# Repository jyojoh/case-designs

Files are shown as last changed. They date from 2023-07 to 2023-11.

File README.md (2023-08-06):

# case-designs
Repository containing STL/STEP files and documentation for my keyboard case designs.  

<p align="center">
<a href="https://discord.gg/P8n4zPxJH5">
  
</a>
</p>

> [!WARNING]
> Please read all enclosed information within the README files in each subfolder for the case that you want to use! There is vital information about battery compatibility, fasteners, and assembly instructions written for each case design!

## Currently Maintained Designs
1. [Choc 5-column Corne](/corne/5-column%20Choc)
2. [Choc 6-column Corne](/corne/6-column%20Choc)
3. MX 6-column Corne (Planned)
   
## Completed/Retired Projects

## Manufacturing Notes
> [!NOTE] 
>All images of cases displayed in this repository are of prototypes manufactured through the CNC-machining services provided by [PCBWay](https://pcbway.com). They are my preferred way for quickly getting prototypes. A lower-cost (and lower quality) alternative would be [JLCPCB](https://jlcpcb.com). Their manufacturing capabilities are more limited, cases received from them have had noticeable machining marks even after bead-blasting. Conversely, the resin 3D-printing services from [JLCPCB](https://jlcpcb.com) are excellent and provided at very reasonable cost. Would highly recommend ordering resin prints to check dimensional correctness, and then proceeding with CNC-machining after verifying. Resin printing is also well-suited for buttons and power switch sliders pieces.

## License
Individuals are free to use the files in this repository for the manufacturing of their own cases. For commercial use, all that is required is providing attribution to  the original designer and linking to this repository in materials distributed for the sales of cases manufactured from the design files here and any derivatives. Attribution materials include the notice in the root directory of this repository.

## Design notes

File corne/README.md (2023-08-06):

# Typeractive Corne
5-col preview
The subfolders here contain production files (.STEP, .STL) for the Corne PCBs found at [Typeractive](https://typeractive.xyz). Please read the following materials closely to ensure proper preparation of parts and subsequent assembly. 

## Introduction
### Required Components (Bare minimum useable keyboard)
1. Case (Left and Right Halves)
1. 2 x [Typeractive Corne PCB](https://typeractive.xyz/products/corne-partially-assembled-pcb)
1. 2 x [nice!nano v2](https://typeractive.xyz/products/nice-nano)
1. 2 x LiPo Batteries:
    - Standard Cases: 803450 1600mAh LiPo Battery 
    - Inset Cases: 503450 1000 mAh LiPo Battery
    - Flat/Legged Cases: 303450 600 mAh LiPo Battery
1. 36/42 x Kailh Choc v1 Switches (Quantities for 5-column/6-column)
1. 36/42 x Keycaps (Pictured are MCC POM)
1. 10 x Brass Standoffs:
    - Tented Cases: 4mm Female to 3mm Male M2 Standoffs
    - Inset Cases: 3mm Female to 3mm Male M2 Standoffs
1. 10 x M2x3mm Bolts
1. 10 x [M2x3mm Heatset Inserts](https://a.co/d/eyAmOag) **(Only if 3D-printing the Heatset Variants)**

### Optional Components **(Highly Recommended!)**
1. 2 x [nice!view Displays](https://typeractive.xyz/products/nice-view)
1. 2 x [Display Covers](displayCover.dxf)
1. 4 x M2x10mm Standoffs
1. 4 x Additional M2x3mm Bolts
1. 1+ x [buttonSlider.stl](buttonSlider.stl) or [buttonSliderSlim.stl](buttonSliderSlim.stl) (for slim cases) which includes already print-plated:
    - 2 x Power Switch Slider (3D-resin printed)
    - 2 x Reset Button Bumper (3D-resin printed)
1. 4 x SKUF Silicone Rubber Feet

All of the listed parts can be bought through Typeractive, except for the case components, fasteners, batteries, and SKUF feet. 

## Manufacturing Notes
1. You only need to print 1 x [buttonSlider.stl](buttonSlider.stl) or [buttonSliderSlim.stl](buttonSliderSlim.stl) depending on the case design, however it is recommended that you print at least one extra to accomodate any mistakes in the post-processing of the printed pieces. One print of the STL includes 2 x power sliders and 2 x reset bumpers to be cut/snapped apart.
2. Recommended manufacturer for the case is [PCBWay](https://pcbway.com), manufacturer for the printed button/slider is [JLCPCB](https://jlcpcb.com).
3. Material used for [buttonSlider.stl](buttonSlider.stl) and [buttonSliderSlim.stl](buttonSliderSlim.stl) is SLA "Black Resin", bead-blasted polycarbonate for the case in the included pictures.
1. **Machining the case designs using metal materials could result in connectivity issues, due to the signal wave-blocking properties of metal. Do so at your own risk!**

## Assembly
1. Assemble the keyboard sans-case as per the [documentation](https://docs.typeractive.xyz/build-guides/corne-wireless) on the Typeractive site.
2. Carefully screw female/male standoffs into each half of the case body. Be careful not to overtighten, and ensure it is perpendicular to the interior of the case!
3. Using flush cutters, separate the power slider and reset button extension from the 3D-printed part. 
4. Insert power slider and reset button extension into their respective slots in the case.
5. At an angle, slide the PCB/Plate assembly of the Corne into the case, ensuring the power switch and reset button on the PCB interface correctly with the slider/extension.
6. Bolt down PCB, apply switches and keycaps, flash as per the firmware [documentation](https://docs.typeractive.xyz/build-guides/corne-wireless)  on the Typeractive site.

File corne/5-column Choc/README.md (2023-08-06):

All case designs listed are derivatives of the "Standard" case. Unless otherwise noted, all case designs are tented by 5 degrees. 

5-col preview

## In this folder:

1. [Standard](/corne/5-column%20Choc/Standard): Tray Mount. 5mm thick walls, 1-piece design suitable for CNC or 3D-printing. 
1. [Standard-Flat](/corne/5-column%20Choc/Standard-Flat): Tray Mount. 5mm thick walls, non-tented. 1-piece design suitable for CNC or 3D-printing.
1. [Inset](/corne/5-column%20Choc/Inset): Tray Mount. In all aspects the same as the Standard case, except 1mm shorter in height. Requires 3mm standoffs instead of the usual 4mm. Suitable for CNC or 3D-printing.
1. [Flattest](/corne/5-column%20Choc/Inset-Flat): Tray Mount. In all aspects the same as the Standard case, just as flat and short as possible. Non-tented. Requires 3mm standoffs instead of the usual 4mm. Suitable for CNC or 3D-printing.
1. [Slim](/corne/5-column%20Choc/Slim): Tray Mount. 3mm thick walls, 1-piece design suitable for CNC or 3D-printing. 
1. [Slim-Flat](/corne/5-column%20Choc/Slim-Flat): Tray Mount. 3mm thick walls non-tented. 1-piece design suitable for CNC or 3D-printing. 
1. [Integrated](/corne/5-column%20Choc/Integrated): "Premium", designed with weight bottom in mind. Integrated Plate. 5mm thick walls, tented. 2-piece case design suitable for CNC machining.
1. [Legged](/corne/5-column%20Choc/Legged): Tray Mount. Includes protrusions that can optionally accept heat-set inserts for the installation of tenting legs. 5mm thick walls, 1-piece design suitable for CNC or 3D-printing. 

**Heatset variants of cases are included for FDM 3D-printing! The nominal hole size is 3.3mm, suitable for inserts with a 3.2mm OD.**
## CNC Data Preparation
When filling out the CNC manufacturing form through [PCBWay](https://pcbway.com), make sure to pay close attention to the following parameters:

1. Specify the desired surface finish. This will most likely be "bead-blasting". 
2. Specify that threaded holes are needed, and upload [threadDrawing.png](/corne/threadDrawing.png) to denote which holes need to be threaded for the M2 female/male standoffs.
3. If the surface finish of the part is of importance to you (it is for me), check the "Premium Finish" option. Note that this will result in a noticeable increase in price. 

## 3D-Printing Data Preparation
For a more budget-friendly version, you may choose to have the case along with the button and slider resin-printed instead through [JLCPCB](https://jlcpcb.com). Pay close attention to the follow parameters:

1. Specify the desired material. My choice for this would be SLA "Imagine Black".
2. You will notice that there is no "threading" option available on JLCPCB's 3D printing form. You will have to force-thread the standoffs yourself. This will almost certainly cause the holes to strip out first, an acceptable compromise as the friction should still hold the standoff firmly in place. 
3. Ensure that the sanding option is set to "Yes". This will greatly improve surface finish quality at little to no extra cost.

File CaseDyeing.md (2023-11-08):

# Dyeing Polycarbonate Cases

## Introduction
### Materials
1. Whichever polycarbonate case you want to dye
1. iDye Poly Dye Packet
1. Large pot (big enough to comfortably submerge your case entirely)
1. Suitable heat source, such as a stovetop
1. Thin Insulated wire
1. Mesh/Wire Basket to hold case, or large perforated ladle

When dyeing polycarbonate cases, there are 2 major factors that will dictate how quickly the color dye will penetrate the material: time, and temperature. The former is self-explanatory, the longer the item is submerged, the more the dye penetrates the material. For the latter, as temperature increases the dye will more easily penetrate the material. To illustrate, a case submerged in a near-boil solution of dye and water will be much darker than a case submerged in a lukewarm solution, when both are submerged for the same amount of time. 

### General Tips
1. Maintain constant agitation of the solution around the case in order to ensure an even coloring. 
1. Maintain constant temperature, or dye both pieces at once if working with multi-part case designs, to ensure even coloring. 
1. Ensure that the surrounding area is well-covered with waterproof materials, as any droplets of dye will quickly color surfaces that it comes into contact with, clothing included. 

> [!WARNING]  
> Always ensure that the solution remains below the boiling point! Boiling the solution will cause droplets of dye to fly out of the container and potentially permanently color the surrounding surfaces. 

> [!Important]
> Rinse the cases thoroughly after each application of dye. The cases will appear to be much darker in color upon first raising them out of the dye solution, however much of this color washes out. 

## Steps
1. Drop the iDye Poly dye pack into a volume of water that comfortably covers your polycarbonate case pieces when they are resting on the ladle at the bottom of the pot. 

> [!Note]
> If you desire a "solid", dark color, then you can opt to apply the dye strengthener pack as well. This will allow the dye to very quickly penetrate the material, resulting in a much darker color. 

2. Bring the solution to a simmer. Wait for all of the dye to completely dissolve into solution. 
1. Using the ladle or mesh basket, lower the pieces into the solution. Start a timer. 
1. Continuously agitate the solution around the case by:
    - Tying the thin wire around the USB port cutout, and jostling it continuously in the solution. Take care that the surface of the wire is insulated, as to prevent bare metal from scratching the case around the cutout. Additionally, ensure that the wire is thin enough to freely move in the port cutout, so as to not constantly be in contact with the interior faces, resulting in uneven dye coloring. 
    -  "Bouncing" the piece up and down by quickly lowering the ladle/basket, then catching the slower-falling case. Ensure that the surface of the ladle does not stay at the same point of contact with the case, as this may cause the ladle to become "imprinted" in the coloring of the case. 

> [!Important]
> Remember that polycarbonate is a relatively soft material when compared to the surfaces of any stainless steel utensils or the interior of the pot you are using! Take care in avoiding scrapes or harsh bumps when stirring and agitating the solution!

5. At regular intervals, such as every 3 minutes, take the case out and rinse thoroughly, revealing the true extent of the coloration. Scrubbing the case with your fingers is recommended. Stop and resume the timer every time this step is taken. Repeat until satisfied. 
1. If any additional parts need to be matched in color, repeat steps 3 to 5 until the piece matches in color to the first.

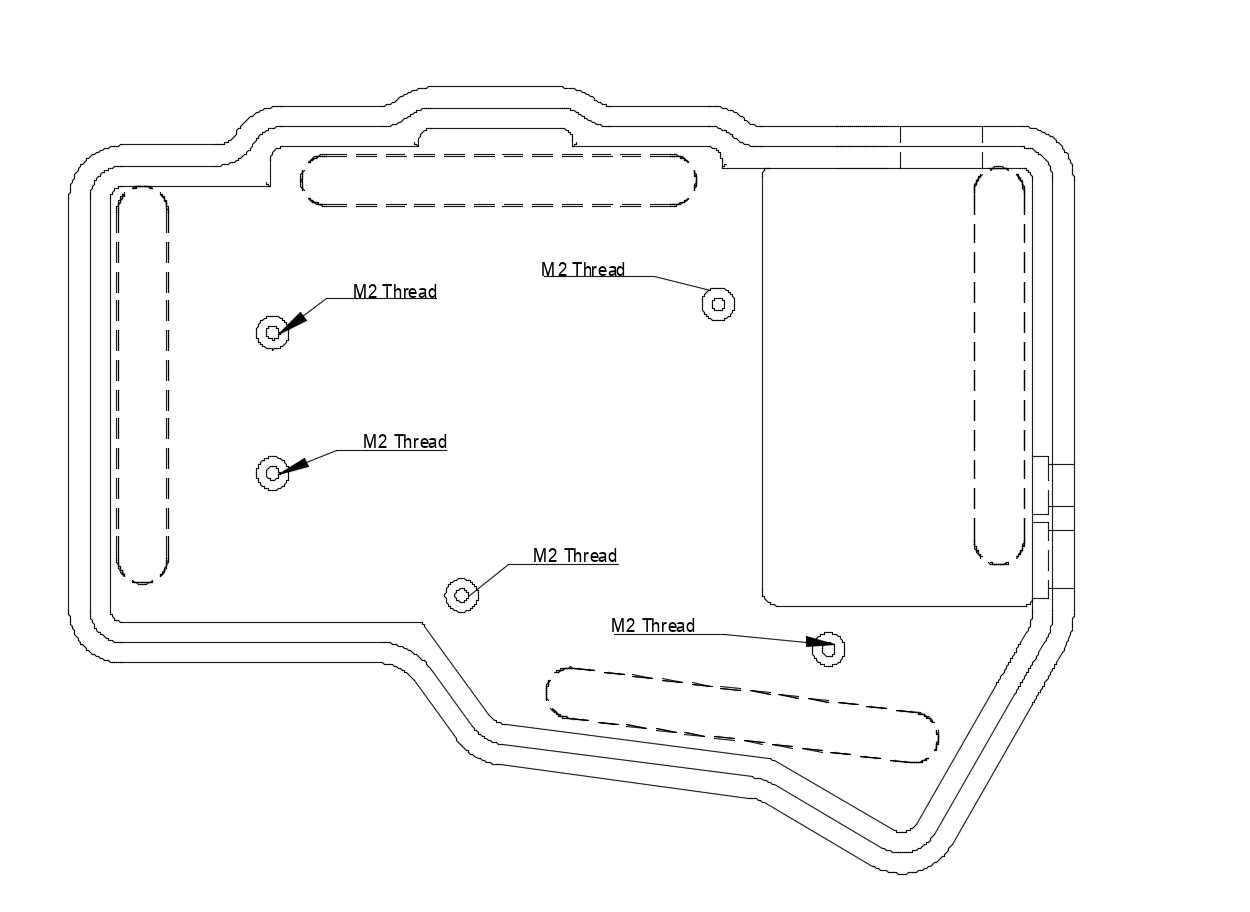
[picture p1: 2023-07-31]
corne/threadDrawing.png

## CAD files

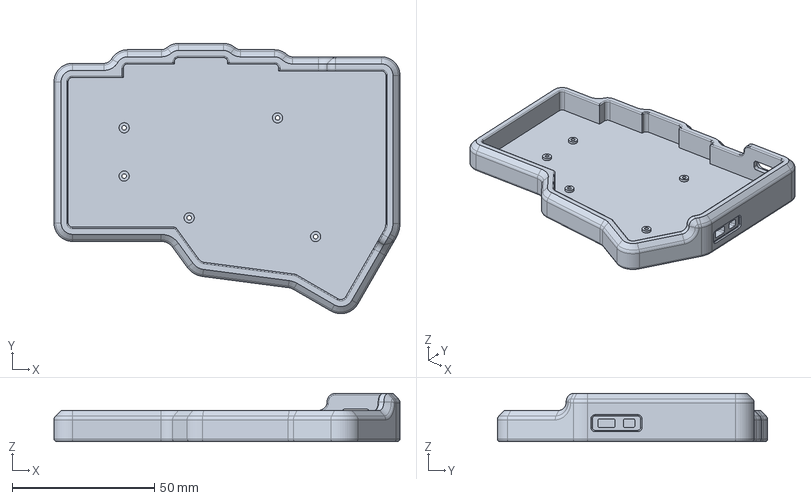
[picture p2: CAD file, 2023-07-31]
corne/5-column Choc/Flattest/leftFlattest.step
121.8 x 95.2 x 17.0 mm

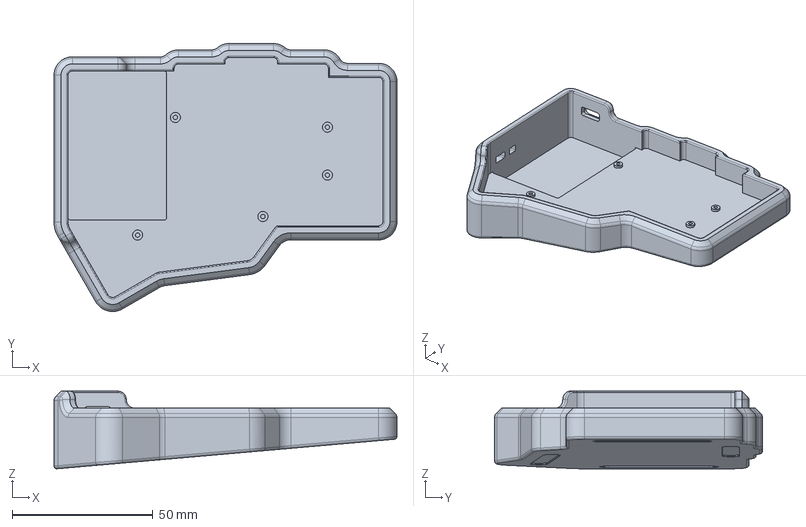
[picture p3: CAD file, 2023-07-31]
corne/5-column Choc/Inset/rightInset.step
121.8 x 95.2 x 27.6 mm

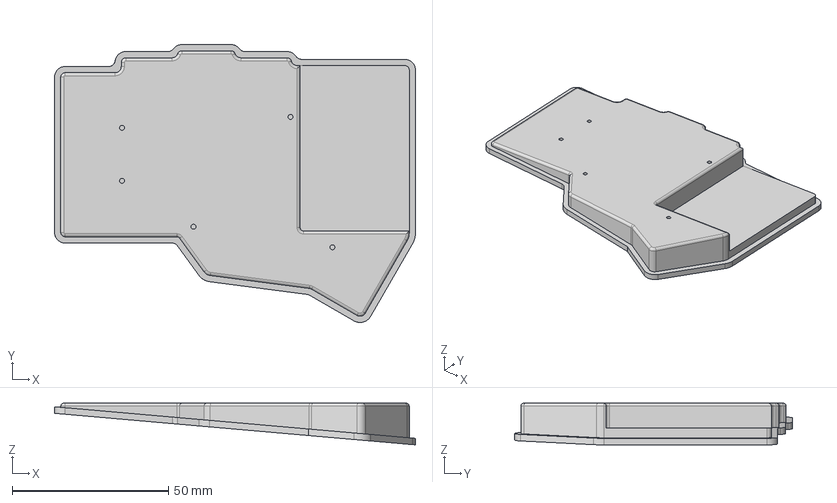
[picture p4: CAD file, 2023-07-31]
corne/5-column Choc/Integrated/leftIntegratedBottom.step
115.7 x 89.1 x 13.4 mm

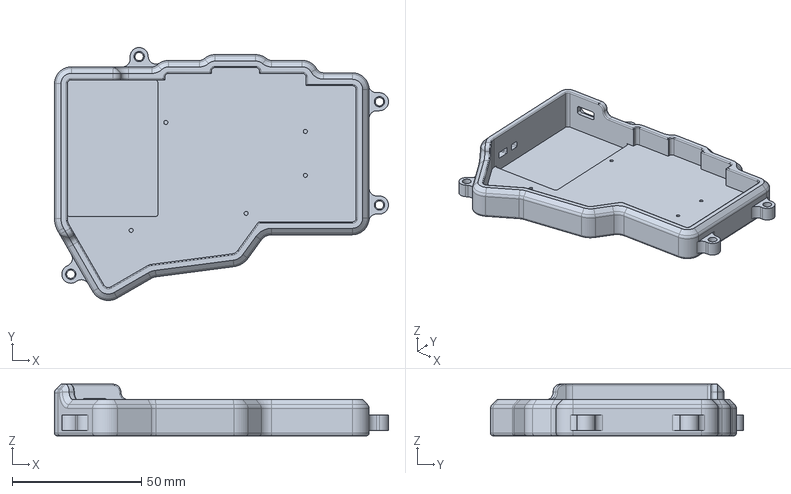
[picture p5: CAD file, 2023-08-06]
corne/5-column Choc/Legged/rightLegged.step
129.3 x 97.9 x 20.0 mm

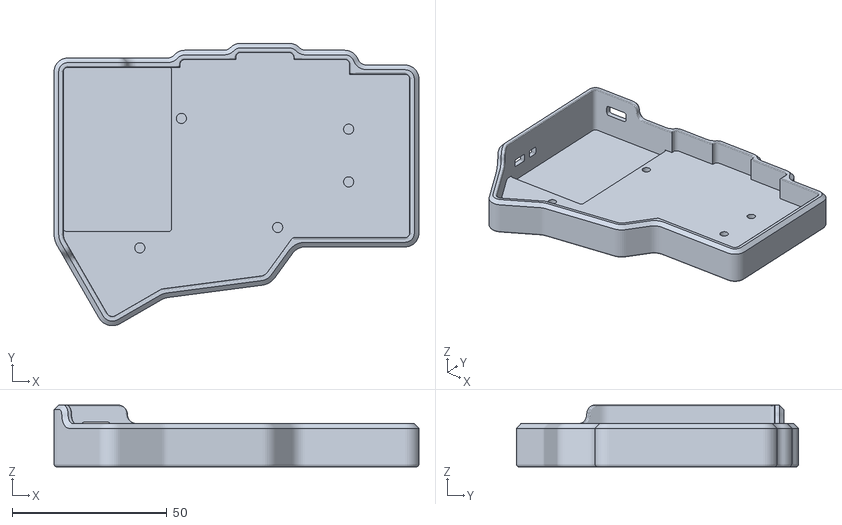
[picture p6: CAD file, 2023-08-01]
corne/5-column Choc/Slim-Flat/rightSlimFlat-Heatset.stl
117.8 x 91.2 x 20.0

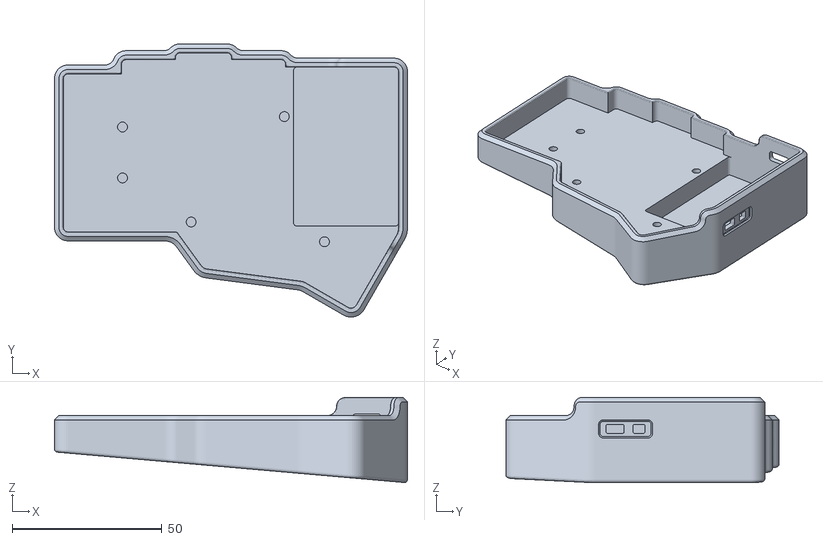
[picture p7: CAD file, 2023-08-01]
corne/5-column Choc/Slim/leftSlim-Heatset.stl
117.8 x 91.2 x 28.4

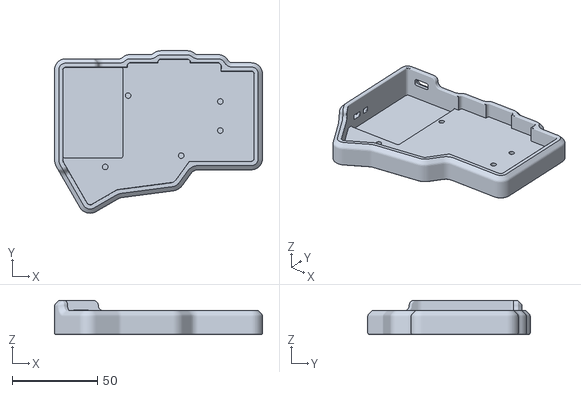
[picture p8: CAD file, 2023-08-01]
corne/5-column Choc/Standard-Flat/rightStandardFlat-Heatset.stl
121.8 x 95.2 x 20.0

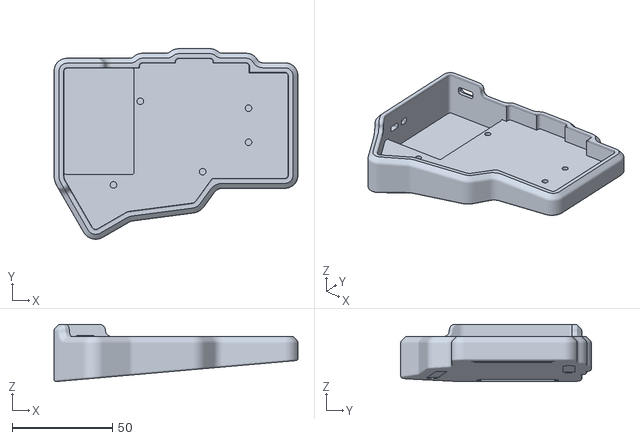
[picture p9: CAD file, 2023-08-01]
corne/5-column Choc/Standard/rightStandard-Heatset.stl
121.8 x 95.2 x 28.6

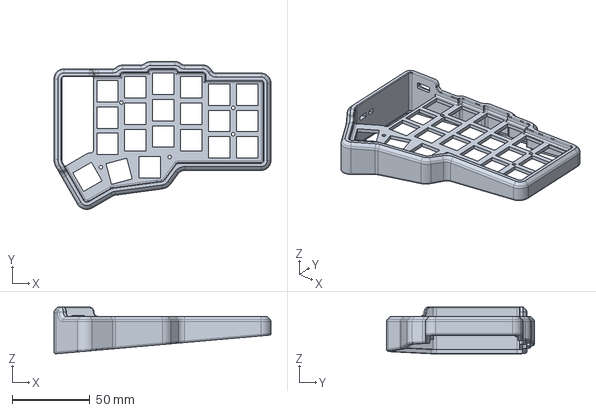
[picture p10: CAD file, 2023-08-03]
corne/6-column Choc/Integrated/rightIntegratedSix.step
139.9 x 95.3 x 30.1 mm

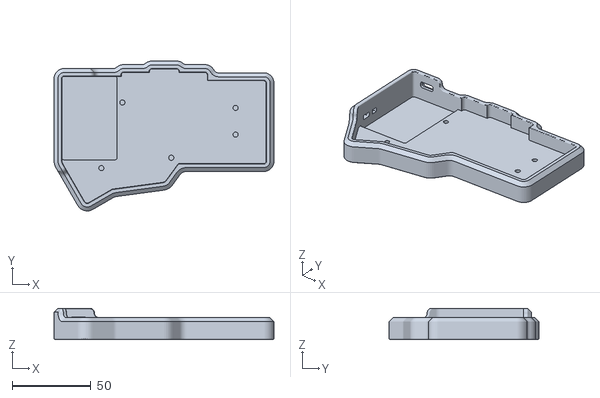
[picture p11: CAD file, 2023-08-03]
corne/6-column Choc/Standard-Flat/rightStandardFlatSix-Heatset.stl
139.9 x 95.3 x 20.0

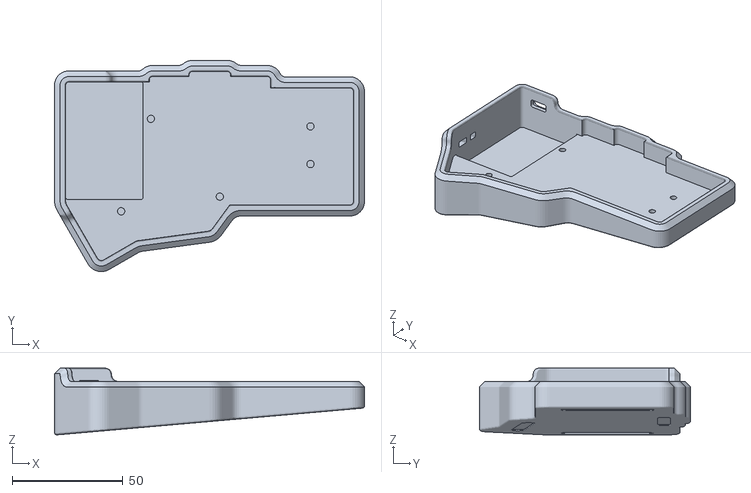
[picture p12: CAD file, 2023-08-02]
corne/6-column Choc/Standard/rightStandardSix-Heatset.stl
139.9 x 95.3 x 30.1

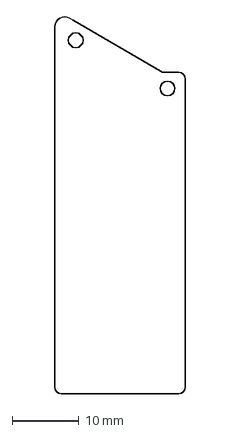
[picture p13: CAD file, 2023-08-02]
corne/displayCover.dxf
19.5 x 56.4 mm

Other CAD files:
corne/5-column Choc/Flattest/rightFlattest.step
corne/5-column Choc/Inset/leftInset.step
corne/5-column Choc/Integrated/rightIntegratedBottom.step
corne/5-column Choc/Legged/leftLegged.step
corne/5-column Choc/Slim-Flat/leftSlimFlat-Heatset.stl
corne/5-column Choc/Slim/rightSlim-Heatset.stl
corne/5-column Choc/Flattest/leftFlattest.stl
corne/5-column Choc/Flattest/rightFlattest.stl
corne/5-column Choc/Inset/leftInset.stl
corne/5-column Choc/Inset/rightInset.stl
corne/5-column Choc/Integrated/leftIntegrated.step
corne/5-column Choc/Integrated/leftIntegrated.stl
corne/5-column Choc/Integrated/leftIntegratedBottom.stl
corne/5-column Choc/Integrated/rightIntegrated.step
corne/5-column Choc/Integrated/rightIntegrated.stl
corne/5-column Choc/Integrated/rightIntegratedBottom.stl
corne/5-column Choc/Legged/leftLegged.stl
corne/5-column Choc/Legged/rightLegged.stl
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

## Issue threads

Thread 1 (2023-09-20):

Original models

mike-engel, 2023-09-20:
Hi! Thank you for providing these cases! I need to make a few modifications for accommodate a slightly larger 600mAh battery, and it would be much easier if I had access to the original design files.

Thanks!

mike-engel, 2023-09-20:
Realized the `step` files represent the solid bodies and can be used as the source 🤦

jyojoh, 2023-09-21:
The "standard" cases are already capable of housing a battery with a capacity larger than 600mAh, they accommodate the  803450 batteries which are typically rated at around 1600mAh

mike-engel, 2023-09-21:
Printing the legged version, my battery is apparently an odd size. Even though it's 600mAh, but it's wider than what's currently designed. Thanks again for making these!

Closed 2023-09-20.

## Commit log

2023-07-25 Add Corne reset button extension and power slider
    [buttonSlider.stl]
2023-07-31 Add display cover DXF
    [displayCover.dxf]
2023-07-31 Updated assembly BOM and instructions
2023-07-31 Include thread drawing
2023-07-31 First batch of 5-col files
    [leftInset.stl, leftIntegrated.stl, leftIntegratedBottom.stl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]
2023-07-31 Additional 5-Col files
    [buttonSlider.stl, leftFlattest.stl, leftSlimFlat.stl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]
2023-07-31 Standard 6-col files
    [leftStandardSix.stl, rightStandardSix.stl]
2023-07-31 Add STEP files for 5-col choc
    [leftFlattest.step, leftInset.step, leftIntegrated.step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]
2023-07-31 Integrated Bottom 5-Col STEP
    [leftIntegratedBottom.step, rightIntegratedBottom.step]
2023-08-01 Battery Spec Correction
2023-08-01 Add slim case buttonSlider and docs
    [buttonSliderSlim.stl]
2023-08-01 5-col choc heatset variants
    [leftSlim-Heatset.stl, leftSlimFlat-Heatset.stl, leftStandard-Heatset.stl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]
2023-08-01 Heatset Disclaimer
2023-08-02 Update displayCover
    [displayCover.dxf]
2023-08-02 STL in Readme test
2023-08-02 Heatset standard for 6 col choc
    [leftStandardSix-Heatset.stl, rightStandardSix-Heatset.stl]
2023-08-03 6 column choc standard flat and integrated
    [leftIntegratedBottomSix.step, leftIntegratedSix.step, leftStandardFlatSix-Heatset.stl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]
2023-08-04 STL Viewer test
    [PREVIEW.stl]
2023-08-04 Revert renderer
    [PREVIEW.stl]
2023-08-06 5 column choc corne legged files
    [leftLegged.step, leftLegged.stl, rightLegged.step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]
